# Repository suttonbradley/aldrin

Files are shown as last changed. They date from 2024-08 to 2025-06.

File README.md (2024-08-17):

# Aldrin Keyboard
Split keyboard designed using ergogen. Inspired by Christian Selig's [dream keyboard video](https://www.youtube.com/watch?v=7UXsD7nSfDY).

## ZMK config
ZMK config for this keyboard is in a separate repo [here](https://github.com/suttonbradley/aldrin-zmk), for the sake of getting firmware from GitHub Actions

## Sourced parts
- [Typeractive](typeractive.xyz)
    - nice!nano
    - Power switch
    - Reset button
    - MX hotswap sockets
    - SMD diodes
    - Machine sockets/pins
    - Battery jack
- PS3 batteries from [Amazon](https://www.amazon.com/dp/B09726K2LC)
- PCBs from [JLCPCB](jlcpcb.com)

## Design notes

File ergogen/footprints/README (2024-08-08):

# About Footprints
FOOTPRINTS COPIED FROM: https://github.com/christianselig/caldera-keyboard/tree/main/ergogen/footprints

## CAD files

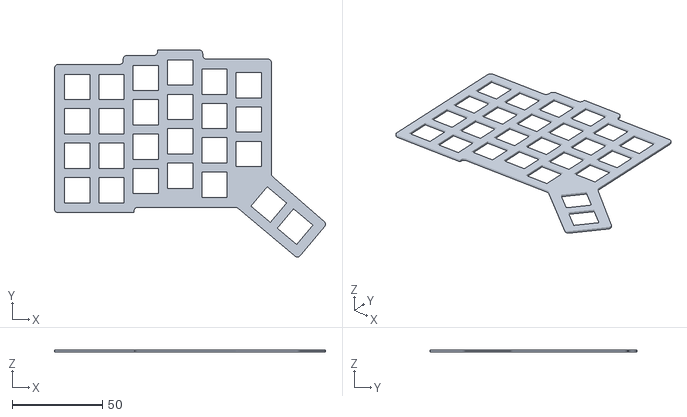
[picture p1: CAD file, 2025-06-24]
ergogen-output/cases/plate v2.stl
149.9 x 114.5 x 1.20

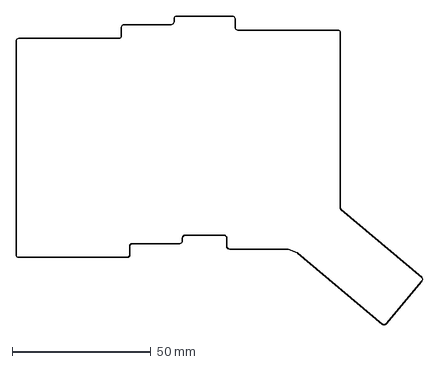
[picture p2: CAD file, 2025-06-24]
ergogen-output/outlines/board_left.dxf
146.8 x 111.3 mm

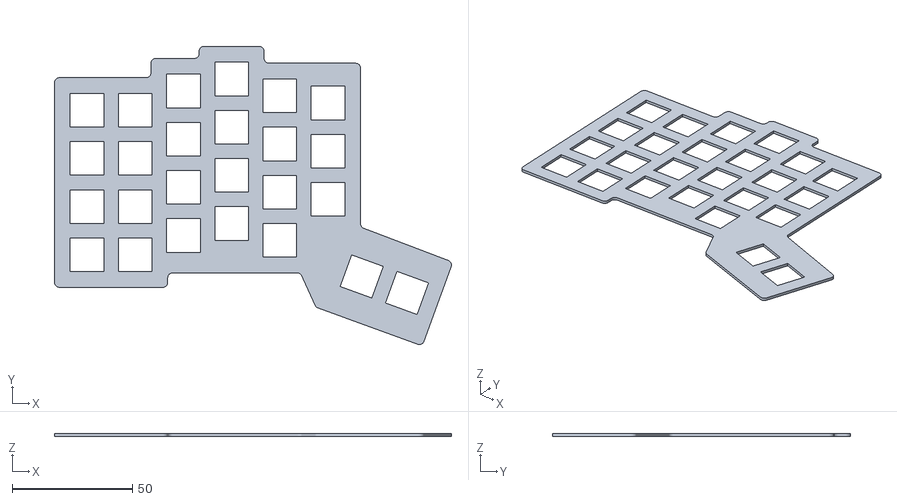
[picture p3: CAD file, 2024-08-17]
ergogen-output/cases/plate_simple.stl
165.1 x 124.0 x 1.20

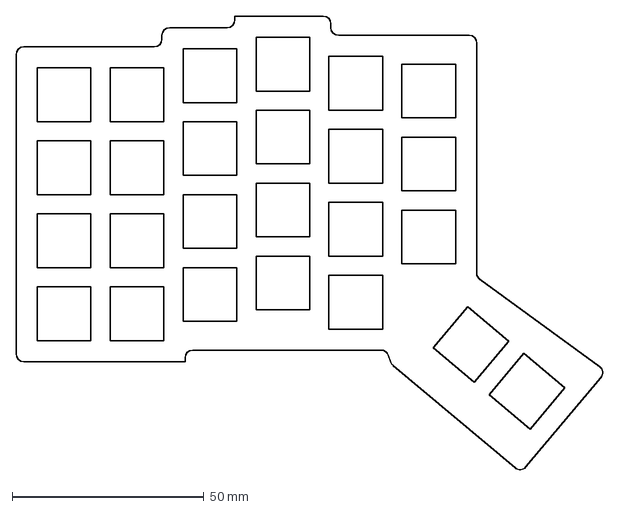
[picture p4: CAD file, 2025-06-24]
ergogen-output/outlines/cutouts_simple.dxf
152.9 x 118.2 mm

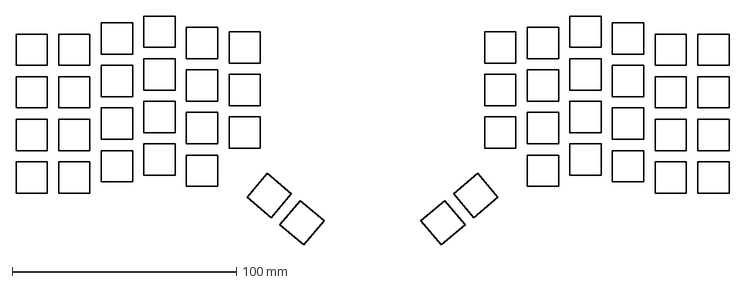
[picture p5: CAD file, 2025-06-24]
ergogen-output/outlines/key_holes.dxf
318.0 x 102.1 mm

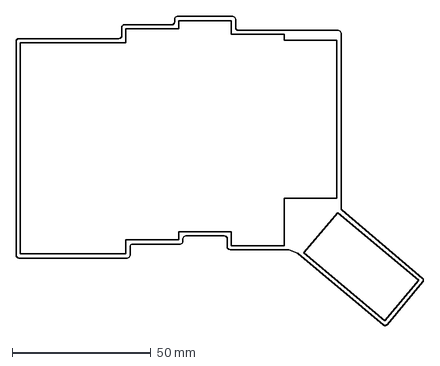
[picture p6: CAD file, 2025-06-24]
ergogen-output/outlines/combo.dxf
146.8 x 111.3 mm

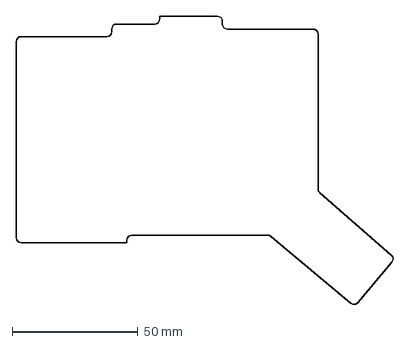
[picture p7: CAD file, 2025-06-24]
ergogen-output/outlines/xl_board_left_simple.dxf
150.1 x 114.5 mm

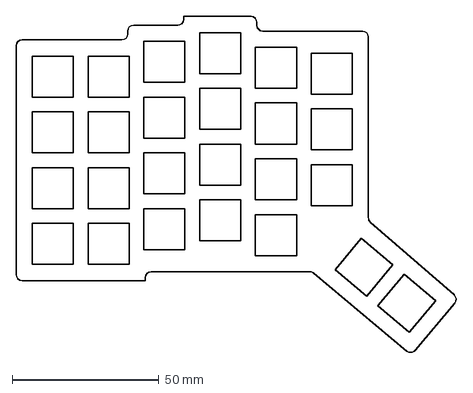
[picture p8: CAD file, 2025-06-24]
ergogen-output/outlines/cutouts.dxf
150.1 x 114.5 mm

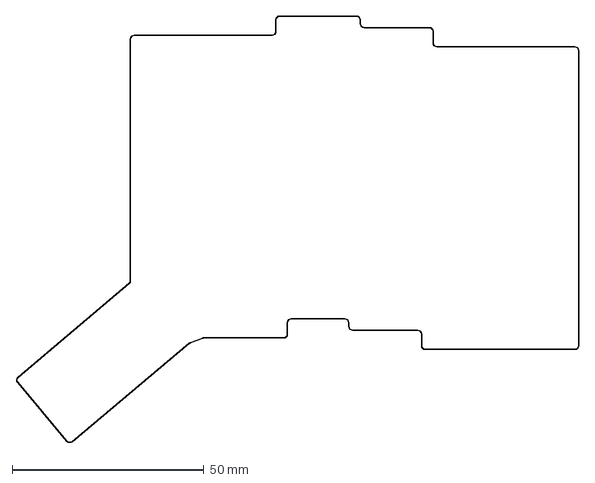
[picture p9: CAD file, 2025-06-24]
ergogen-output/outlines/board_right.dxf
146.8 x 111.4 mm

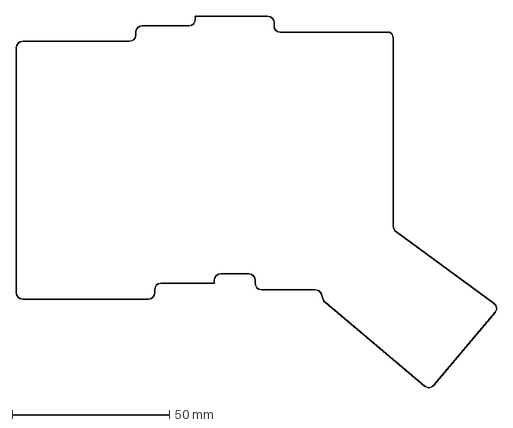
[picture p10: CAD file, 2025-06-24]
ergogen-output/outlines/xl_board_left.dxf
152.9 x 118.2 mm

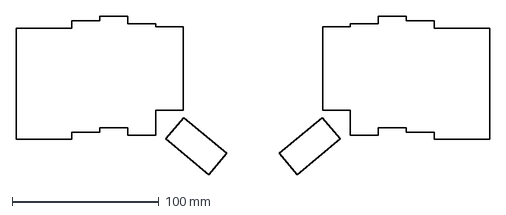
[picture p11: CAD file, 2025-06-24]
ergogen-output/outlines/keys.dxf
323.0 x 108.1 mm

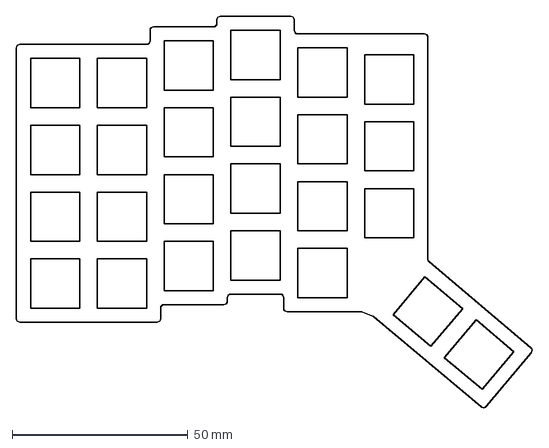
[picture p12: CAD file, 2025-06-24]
ergogen-output/outlines/cutouts_non_xl.dxf
146.8 x 111.3 mm

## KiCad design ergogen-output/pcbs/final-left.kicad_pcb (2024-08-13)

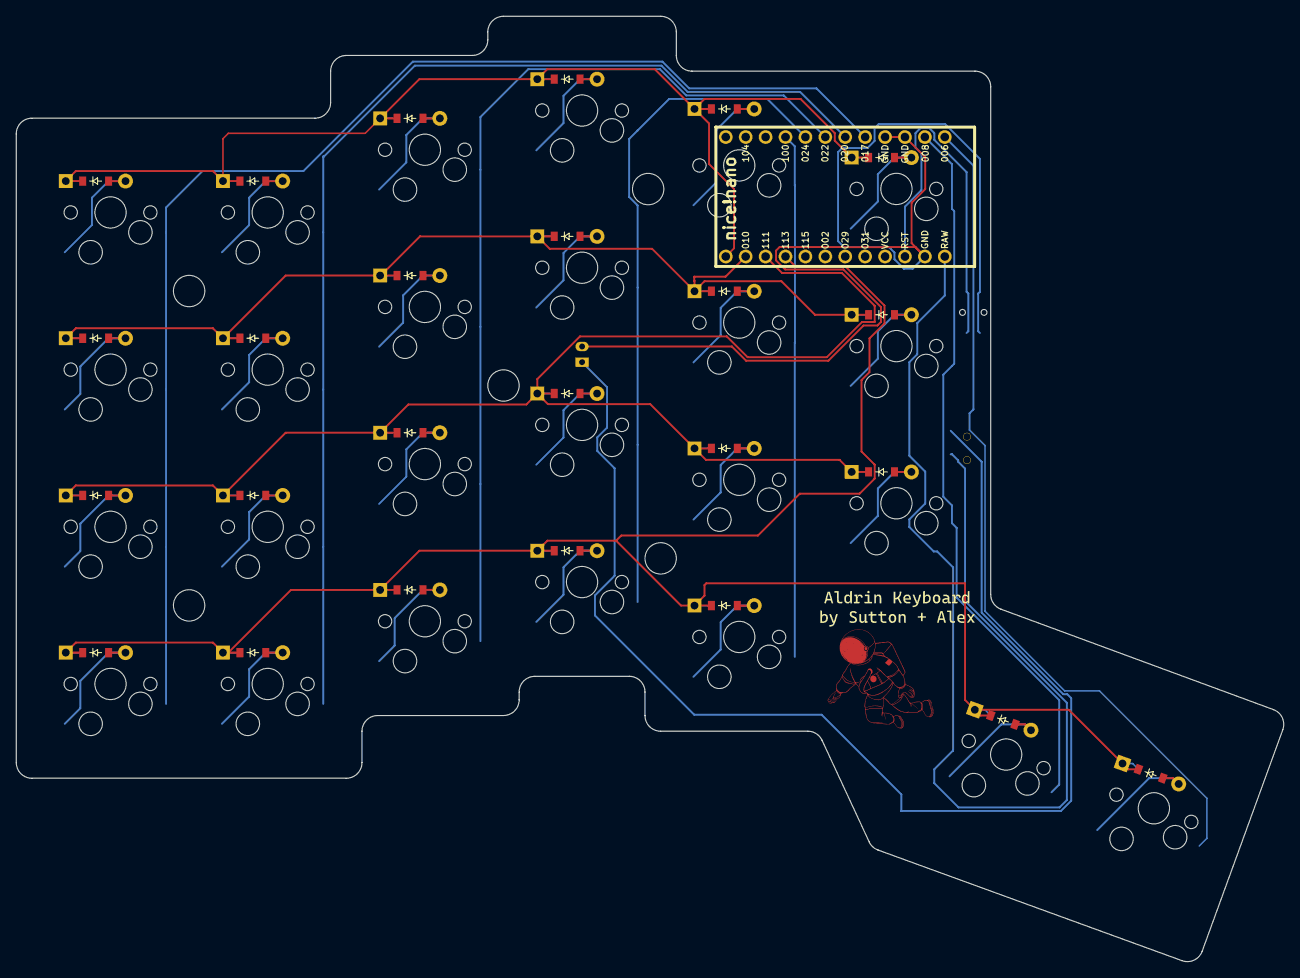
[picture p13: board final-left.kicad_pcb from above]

Board: 2 copper layers, 161.7 x 120.6 mm, 54 parts (0 on the bottom side), 40 nets.

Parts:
B1: Panasonic_EVQPUL_EVQPUC
D1, D2, D3, D4, D5, D6, D7, D8, D9, D10, D11, D12, D13, D14, D15, D16, D17, D18, D19, D20, D21, D22, D23, D24, D25: ComboDiode
JST1: JST_PH_S2B-PH-K_02x2.00mm_Angled
MCU1: nice_nano
S1, S2, S3, S4, S5, S6, S7, S8, S9, S10, S11, S12, S13, S14, S15, S16, S17, S18, S19, S20, S21, S22, S23, S24, S25: MX
T1: SPDT_C128955

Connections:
GND: B1.1, JST1.2, MCU1.3, MCU1.4, MCU1.23
P006: MCU1.1, S25.1
P008: MCU1.2, S21.1, S22.1, S23.1, S24.1
P009: D4.1, D8.1, D12.1, D16.1, D22.1, D25.1, MCU1.13
P010: D3.1, D7.1, D11.1, D15.1, D19.1, D21.1, MCU1.14
P017: MCU1.5, S1.1, S2.1, S3.1, S4.1
P020: MCU1.6, S5.1, S6.1, S7.1, S8.1
P022: MCU1.7, S9.1, S10.1, S11.1, S12.1
P024: MCU1.8, S13.1, S14.1, S15.1, S16.1
P100: MCU1.9, S17.1, S18.1, S19.1, S20.1
P111: D2.1, D6.1, D10.1, D14.1, D18.1, D20.1, MCU1.15
P113: D1.1, D5.1, D9.1, D13.1, D17.1, D23.1, D24.1, MCU1.16
RAW: MCU1.24, T1.2
RST: B1.2, MCU1.22
index_bottom: D18.2, S18.2
index_home: D19.2, S19.2
index_mod: D17.2, S17.2
index_top: D25.2, S20.2
inner_bottom: D20.2, S21.2
inner_first: D23.2, S24.2
inner_home: D21.2, S22.2
inner_top: D22.2, S23.2
middle_bottom: D14.2, S14.2
middle_home: D15.2, S15.2
middle_mod: D13.2, S13.2
middle_top: D16.2, S16.2
outer_bottom: D2.2, S2.2
outer_first: D24.2, S25.2
outer_home: D3.2, S3.2
outer_mod: D1.2, S1.2
outer_top: D4.2, S4.2
pinky_bottom: D6.2, S6.2
pinky_home: D7.2, S7.2
pinky_mod: D5.2, S5.2
pinky_top: D8.2, S8.2
pos: JST1.1, T1.1
ring_bottom: D10.2, S10.2
ring_home: D11.2, S11.2
ring_mod: D9.2, S9.2
ring_top: D12.2, S12.2

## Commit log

2024-08-07 Start PCB
2024-08-07 Add nice_nano footprint
2024-08-07 Use nice nano footprint with no pins or holes for 101, 102, or 107
2024-08-08 Add in footprints for diodes/battery jack/reset switch/battery switch/mounting holes, reduce pad around edge of PCB, use U instead of u
2024-08-08 Make PCB follow bottom of key layout closely
2024-08-08 battery switch placement
2024-08-08 Right half PCB
2024-08-12 Switch around pin hole matching for easier routing
2024-08-12 Fix some stuff specific to right PCB, final pass at pin assignment?
2024-08-12 Add PCB output post-PCB order
    [board_left.dxf, board_right.dxf, combo.dxf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]
2024-08-13 fix pcbs :(
    [final-left.kicad_pcb, final-right.kicad_pcb]
2024-08-13 Ignore gerber files
2024-08-13 fix pcbs part 2
    [final-right.kicad_pcb]
2024-08-13 Fix up PCB one last time
    [final-left.kicad_pcb, final-right.kicad_pcb]
2024-08-13 Make ergogen line up mounting hole with where it was manually adjusted to in kicad
2024-08-17 Remove TODOs as PCBs is now ordered
2024-08-17 Add XL board and cutouts
2024-08-17 Add simplified board option (flat bottom edge)
2024-08-17 Add ergogen output
    [cutouts.dxf, cutouts_non_xl.dxf, cutouts_simple.dxf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]
2024-08-17 Add jscad -> stl conversion
    [plate_simple.stl]
2025-06-23 fix up for board changes
2025-06-23 erase xl board
2025-06-24 modified output
    [board_left.dxf, board_right.dxf, combo.dxf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]
2025-06-24 plate shenanigans
    [plate v2.stl]
